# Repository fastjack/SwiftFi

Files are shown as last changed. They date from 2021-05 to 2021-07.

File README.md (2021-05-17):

# SwiftFi
WiFi interface for Commodore 128D

This is an attempt at an internal WiFi modem for the Commodore 128D based on the SwiftLink cartridge as described in https://www.commodoreserver.com/BlogEntryView.asp?EID=FA5AE758474345A9A0A7208C7F408538

The PCB's dimensions were tailored for a C128D(DCR) mainboard since this is the only model of C128 I have available.

The PCB is sandwiched between U1 (CIA). Two additional signals need to be routed to this PCB. DOTCLK can be tapped from pin 6 on the expansion port. CS (chip select) can be tapped from (the unused) pin 16 of U3.

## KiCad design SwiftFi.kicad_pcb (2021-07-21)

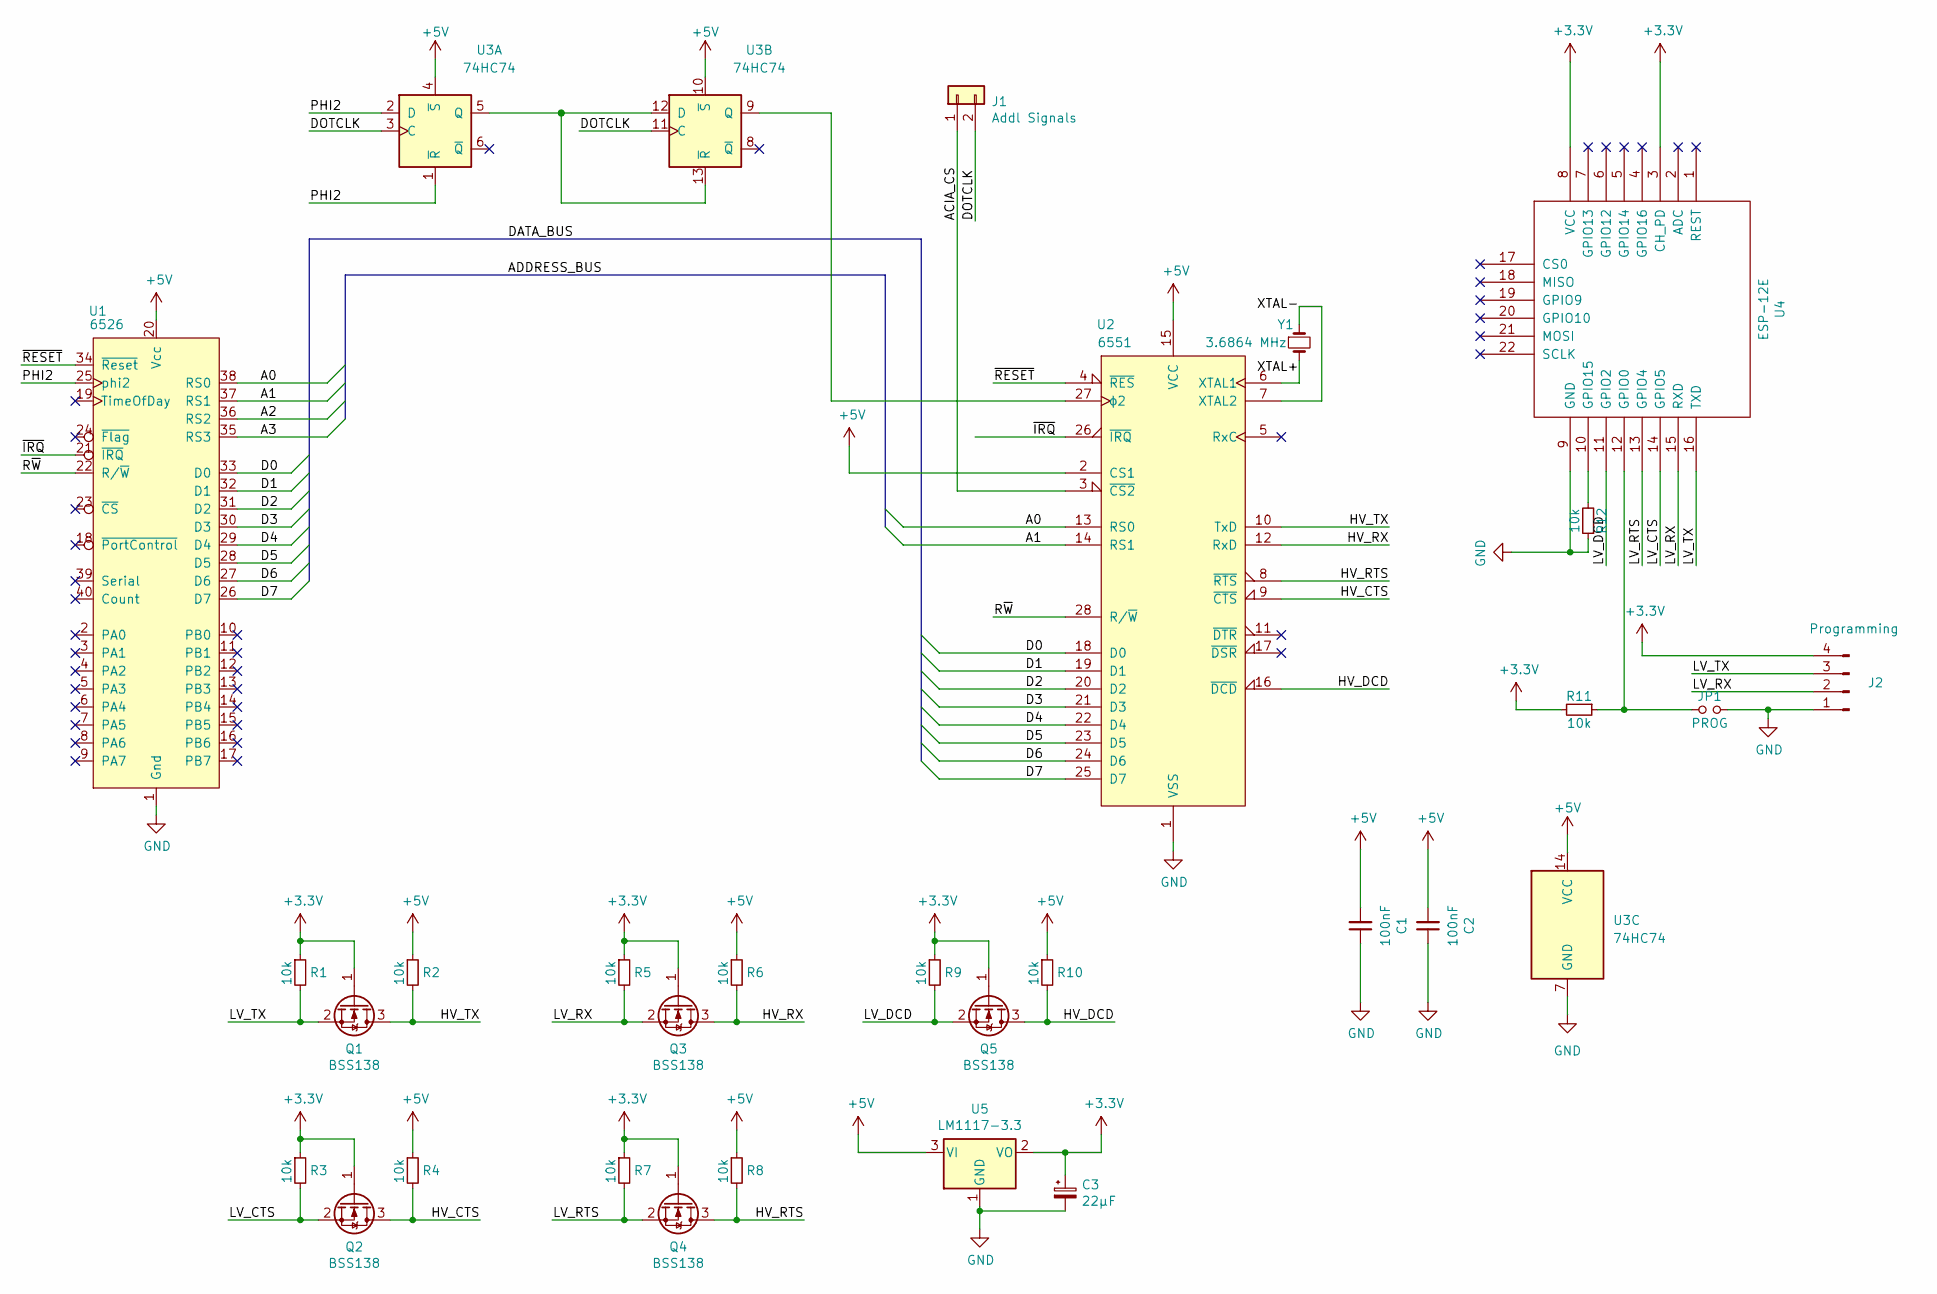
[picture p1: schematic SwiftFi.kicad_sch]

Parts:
C1, C2: 100nF; CP_EIA-3216-10_Kemet-I_Pad1.58x1.35mm_HandSolder; Digikey 478-8926-1-ND
C3: 22µF; CP_EIA-3216-10_Kemet-I_Pad1.58x1.35mm_HandSolder; Digikey 478-8429-1-ND
J1: Addl Signals; PinHeader_1x02_P2.54mm_Vertical; Digikey S1022E-02-ND
J2: Programming; PinHeader_1x04_P2.54mm_Vertical; Digikey S1222E-04-ND
JP1: PROG; PinHeader_1x02_P2.54mm_Vertical; Digikey S1022E-02-ND
Q1, Q2, Q3, Q4, Q5: BSS138; SOT-23; Digikey BSS138CT-ND
R1, R2, R3, R4, R5, R6, R7, R8, R9, R10, R11, R12: 10k; R_0603_1608Metric; Digikey 2368-SR1-0603-610-ND
U1: 6526; DIP-40_W15.24mm_Socket; Digikey ED3048-5-ND
U2: 6551; DIP-28_W15.24mm_Socket; Digikey 1175-1490-ND
U3: 74HC74; DIP-14_W7.62mm; Digikey 296-1602-5-ND
U4: ESP-12E; Digikey ESP-12SRF-ND
U5: LM1117-3.3; SOT-223; Digikey LM1117IMP-3.3/NOPBCT-ND
Y1: 3.6864 MHz; HC49%2fUS; Digikey XC1236CT-ND

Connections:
+3V3: C3.1, J2.4, Q1.1 (G), Q2.1 (G), Q3.1 (G), Q4.1 (G), Q5.1 (G), R1.1, R3.1, R5.1, R7.1, R9.1, R11.2, U4.3 (CH_PD), U4.8 (VCC), U5.2 (VO)
+5V: C1.2, C2.2, R2.1, R4.1, R6.1, R8.1, R10.1, U1.20 (Vcc), U2.2 (CS1), U2.15 (VCC), U3.4 (~S), U3.10 (~S), U3.14 (VCC), U5.3 (VI)
/A0: U1.38 (RS0), U2.13 (RS0)
/A1: U1.37 (RS1), U2.14 (RS1)
/A2: U1.36 (RS2)
/A3: U1.35 (RS3)
/ACIA_CS: J1.1, U2.3 (~CS2)
/D0: U1.33 (D0), U2.18 (D0)
/D1: U1.32 (D1), U2.19 (D1)
/D2: U1.31 (D2), U2.20 (D2)
/D3: U1.30 (D3), U2.21 (D3)
/D4: U1.29 (D4), U2.22 (D4)
/D5: U1.28 (D5), U2.23 (D5)
/D6: U1.27 (D6), U2.24 (D6)
/D7: U1.26 (D7), U2.25 (D7)
/DOTCLK: J1.2, U3.3 (C), U3.11 (C)
/HV_CTS: Q2.3 (D), R4.2, U2.9 (~CTS)
/HV_DCD: Q5.3 (D), R10.2, U2.16 (~DCD)
/HV_RTS: Q4.3 (D), R8.2, U2.8 (~RTS)
/HV_RX: Q3.3 (D), R6.2, U2.12 (RxD)
/HV_TX: Q1.3 (D), R2.2, U2.10 (TxD)
/LV_CTS: Q2.2 (S), R3.2, U4.14 (GPIO5)
/LV_DCD: Q5.2 (S), R9.2, U4.11 (GPIO2)
/LV_RTS: Q4.2 (S), R7.2, U4.13 (GPIO4)
/LV_RX: J2.2, Q3.2 (S), R5.2, U4.15 (RXD)
/LV_TX: J2.3, Q1.2 (S), R1.2, U4.16 (TXD)
/PHI2: U1.25 (phi2), U3.1 (~R), U3.2 (D)
/R~W: U1.22 (R/~W), U2.28 (R/~W)
/XTAL+: U2.6 (XTAL1), Y1.2
/XTAL-: U2.7 (XTAL2), Y1.1
/~IRQ: U1.21 (~IRQ), U2.26 (~IRQ)
/~RESET: U1.34 (~Reset), U2.4 (~RES)
GND: C1.1, C2.1, C3.2, J2.1, JP1.2, R12.1, U1.1 (Gnd), U2.1 (VSS), U3.7 (GND), U4.9 (GND), U5.1 (GND)
unnamed: JP1.1, R11.1, U4.12 (GPIO0)
unnamed: R12.2, U4.10 (GPIO15)
unnamed: U2.27 (ϕ2), U3.9 (Q)
unnamed: U3.5 (Q), U3.12 (D), U3.13 (~R)

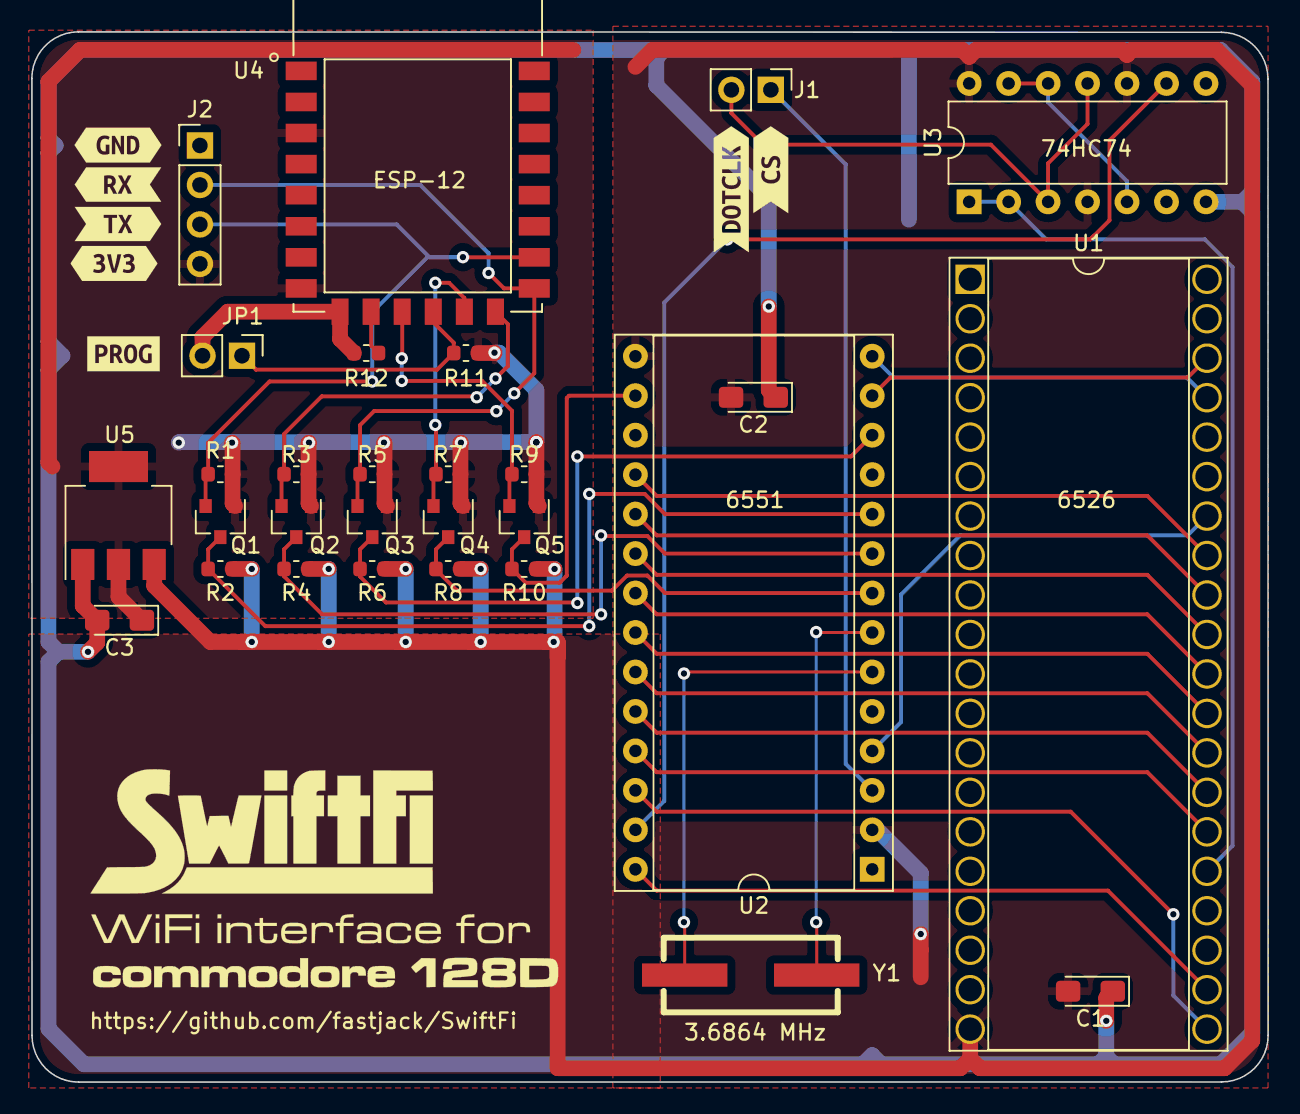
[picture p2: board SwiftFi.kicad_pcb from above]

Board: 2 copper layers, 79.6 x 67.6 mm, 37 parts (0 on the bottom side), 35 nets.

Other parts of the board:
3V3_LABEL: G***; svg2mod
CS_LABEL: G***; svg2mod
DOTCLK_LABEL: G***; svg2mod
GND_LABEL: G***; svg2mod
PROG_LABEL: G***; svg2mod
RX_LABEL: G***; svg2mod
Ref**: Val**; SwiftFi 8mm
TX_LABEL: G***; svg2mod

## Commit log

2021-05-17 Added GitHub repo URL to PCB silkscreen
    [SwiftFi.kicad_pcb]
2021-05-17 changed footprints caps, added llinks to aliexpress in BOM
    [SwiftFi.kicad_pcb, SwiftFi.kicad_sch]
2021-05-24 Updated design rules to those recommended by OSHPark
    https://docs.oshpark.com/design-tools/kicad/kicad-design-rules/
2021-05-24 ignore overlapping courtyards of bypass caps inside DIP sockets
2021-05-24 enlarged drill holes for pins of CIA
    the individual pins intended to be used here require drill holes of 1.5 mm in diameter
    [SwiftFi.kicad_pcb]
2021-07-21 Updated logo
    [SwiftFi.kicad_pcb]
